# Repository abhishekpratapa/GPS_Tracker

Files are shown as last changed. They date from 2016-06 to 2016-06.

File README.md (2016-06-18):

# GPS_Tracker
A GPS tracker for a 3rd party logistics company. A medium article on how it came to be:<br/> https://medium.com/abhishek-pratapa/the-gps-tracker-842071f3ebae#.iqlriwf8i

<h2>Software</h2>

The software of the tracker consisted of an Arduino sketch and a backend initially built in Node.js however we scrapped that after we didn't have the funds to pay for the twillio api access.<br/>

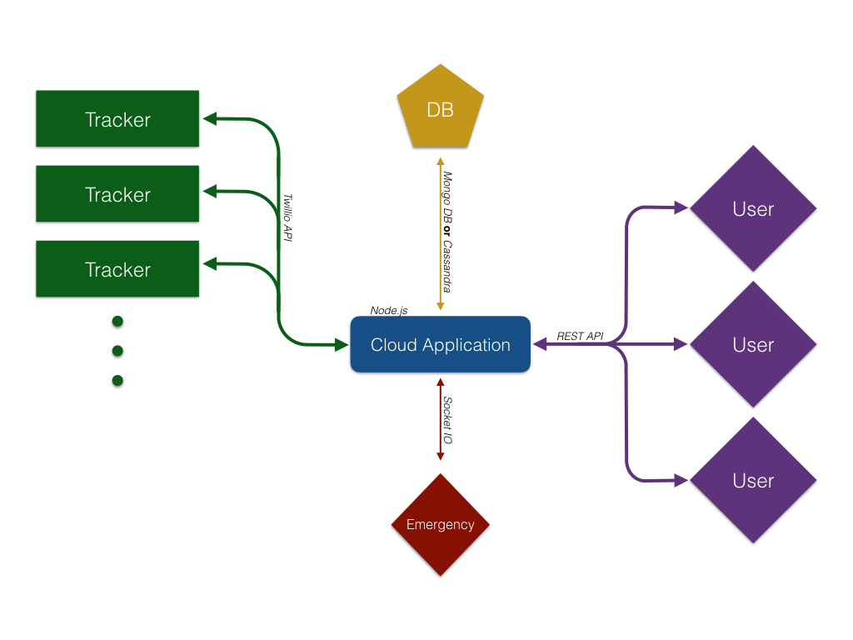
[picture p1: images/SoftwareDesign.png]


<h2>Hardware</h2>

The hardware of the tracker consisted of the below components, a full listing of parts is to follow later. <br/>

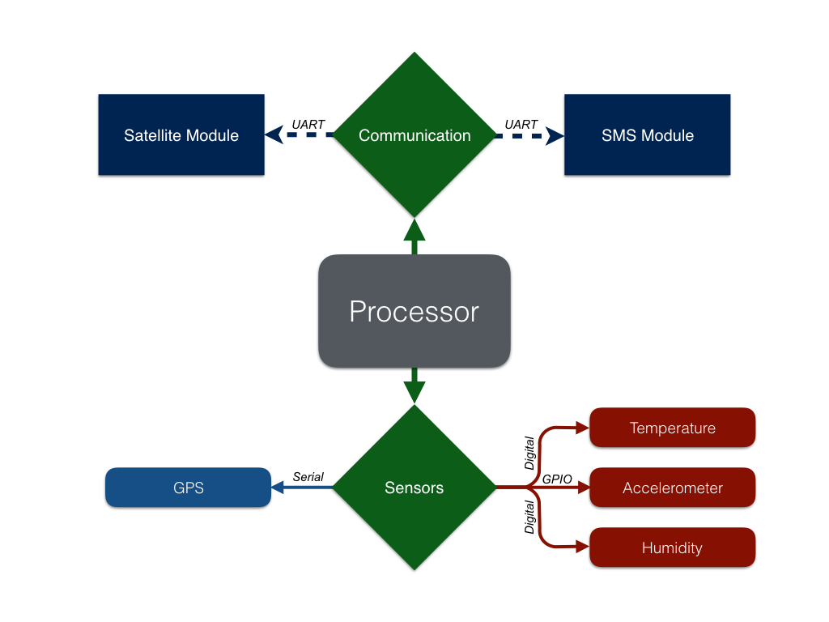
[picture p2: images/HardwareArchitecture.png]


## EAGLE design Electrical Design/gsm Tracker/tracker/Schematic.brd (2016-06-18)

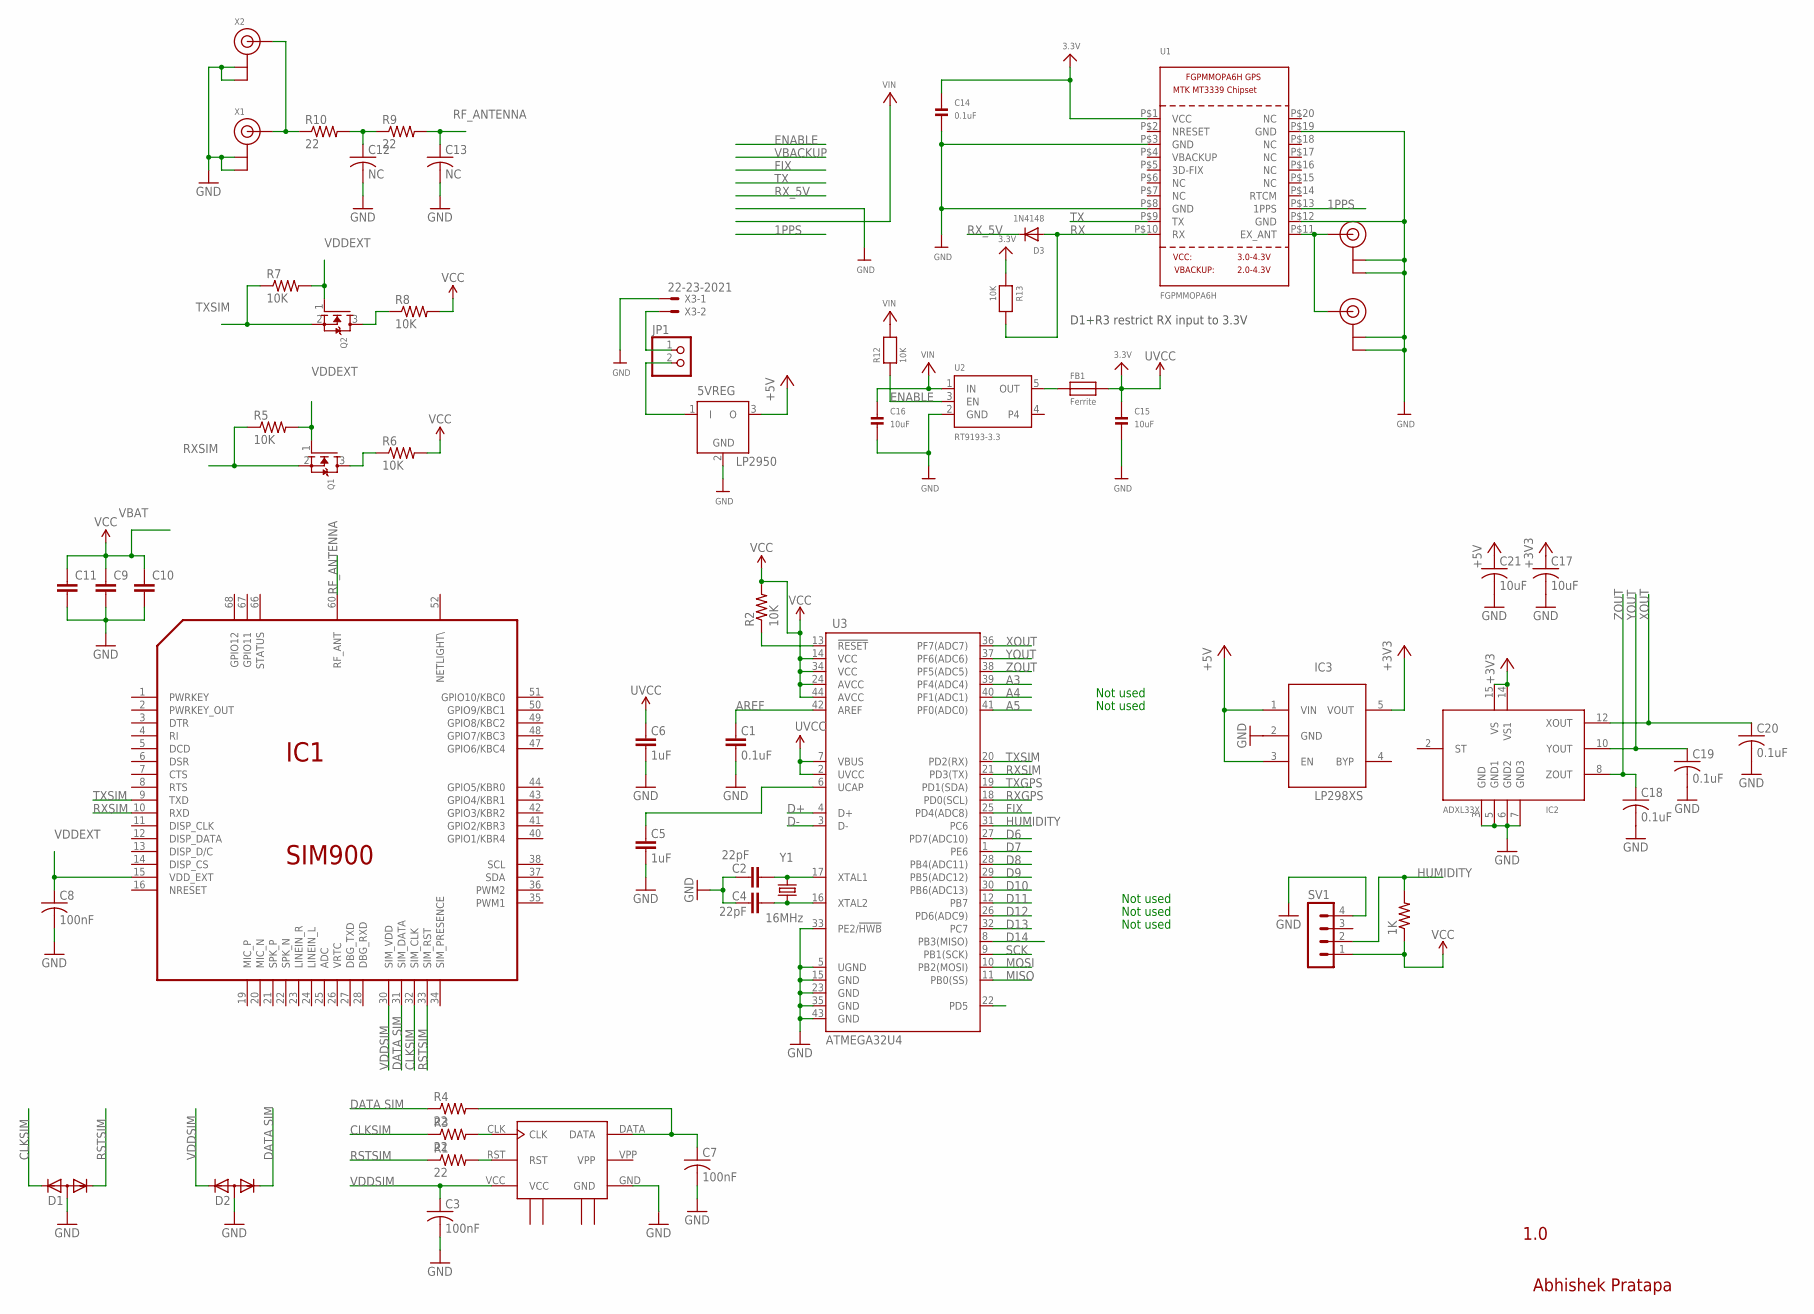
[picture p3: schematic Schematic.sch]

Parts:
1K: R-US_M0805; M0805
5VREG: LP2950; DPACK
C1: 0.1uF; 0603-CAP
C2, C4: 22pF; 0603-CAP
C3, C7, C8: 100nF; C0805
C5, C6: 1uF; 0603-CAP
C9, C10, C11: C-EUC0805; C0805
C12, C13: NC; C0805
C14: 0.1uF; 0805
C15, C16: 10uF; 0805
C17, C21: 10uF; C0805K
C18, C19, C20: 0.1uF; C0805K
D1, D2: DIODE-2CA|ACSOT23; SOT23
D3: 1N4148; SOD-323F
FB1: Ferrite; 0805
IC1: SIM900
IC2: ADXL33X; 16LCSP
IC3: LP298XS; SOT23-5L
JP1: PINHD-1X2; 1X02
Q1, Q2: MOSFET-NREFLOW; SOT23
R1, R3, R4: 22; M0805
R2: 10K; 0603-RES
R5, R6, R7, R8: 10K; M0805
R9, R10: 22; R0805
R12, R13: 10K; 0805
SV1: MA04-1
U1: FGPMMOPA6H
U2: RT9193-3.3; SOT23-5
U3: ATMEGA32U4; QFN-44-NOPAD_1:1-OUTFAKES
U$1: SCU-W0822XR-06
U$8, U$20: U.FL
X1, X2: ANTENNA_U.FL; U.FL
X3: 22-23-2021
Y1: 16MHz; CRYSTAL-SMD-5X3

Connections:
1PPS: U1.P$13 (1PPS)
3.3V: 1K.1, C14.1, C15.1, FB1.2, R13.1, SV1.1, U1.P$1 (VCC)
+3V3: C17.1, IC2.14 (VS1), IC2.15 (VS), IC3.5 (VOUT)
+5V: 5VREG.3 (O), C21.1, IC3.1 (VIN), IC3.3 (EN)
A3: U3.39 (PF4(ADC4))
A4: U3.40 (PF1(ADC1))
A5: U3.41 (PF0(ADC0))
AREF: C1.2, U3.42 (AREF)
CLKSIM: D1.2 (K2), IC1.32 (SIM_CLK), R3.1
D6: U3.27 (PD7(ADC10))
D7: U3.1 (PE6)
D8: U3.28 (PB4(ADC11))
D9: U3.29 (PB5(ADC12))
D10: U3.30 (PB6(ADC13))
D11: U3.12 (PB7)
D12: U3.26 (PD6(ADC9))
D13: U3.32 (PC7)
D14: U3.8 (PB3(MISO))
D+: U3.4 (D+)
D-: U3.3 (D-)
DATASIM: D2.1 (K1), IC1.31 (SIM_DATA), R4.1
ENABLE: R12.1, U2.3 (EN)
FIX: U3.25 (PD4(ADC8))
GND: 5VREG.2 (GND), C1.1, C2.2, C3.2, C4.2, C5.1, C6.1, C7.2, C8.2, C9.2, C10.2, C11.2, C12.2, C13.2, C14.2, C15.2, C16.2, C17.2, C18.2, C19.2, C20.2, C21.2, D1.3 (A), D2.3 (A), IC1.17 (GND), IC1.18 (GND), IC1.29 (GND), IC1.39 (GND), IC1.45 (GND), IC1.46 (GND), IC1.53 (GND), IC1.54 (GND), IC1.58 (GND), IC1.59 (GND), IC1.61 (GND), IC1.62 (GND), IC1.63 (GND), IC1.64 (GND), IC1.65 (GND), IC2.3 (GND), IC2.5 (GND1), IC2.6 (GND2), IC2.7 (GND3), IC3.2 (GND), SV1.4, U1.P$3 (GND), U1.P$8 (GND), U1.P$12 (GND), U1.P$19 (GND), U2.2 (GND), U3.5 (UGND), U3.15 (GND), U3.23 (GND), U3.33 (PE2/!HWB), U3.35 (GND), U3.43 (GND), U$1.GND, U$1.GND_1 (GND1), U$1.GND_2 (GND2), U$1.GND_3 (GND3), U$8.P$1 (GND), U$8.P$2 (GND), U$20.P$1 (GND), U$20.P$2 (GND), X1.1 (GND), X1.2 (GND), X2.1 (GND), X2.2 (GND), X3.1
GND4: U$1.GND_4 (GND4)
HUMIDITY: 1K.2, SV1.2, U3.31 (PC6)
MISO: U3.11 (PB0(SS))
MOSI: U3.10 (PB2(MOSI))
unnamed: C4.1, U3.16 (XTAL2), Y1.1
unnamed: C2.1, U3.17 (XTAL1), Y1.3 (2)
unnamed: R1.2, U$1.RST
unnamed: C5.2, U3.6 (UCAP)
unnamed: R3.2, U$1.CLK
unnamed: C7.1, R4.2, U$1.DATA
unnamed: R10.1, X1.3 (SIGNAL), X2.3 (SIGNAL)
unnamed: C12.1, R9.1, R10.2
unnamed: Q1.3 (D), R6.1
unnamed: Q2.3 (D), R8.1
unnamed: 5VREG.1 (I), JP1.2
unnamed: FB1.1, U2.5 (OUT)
unnamed: U1.P$11 (EX_ANT), U$8.P$3 (SIGNAL), U$20.P$3 (SIGNAL)
unnamed: JP1.1, X3.2
RESET: R2.1, U3.13 (!RESET)
RF_ANTENNA: C13.1, IC1.60 (RF_ANT), R9.2
RSTSIM: D1.1 (K1), IC1.33 (SIM_RST), R1.1
RX: D3.A, R13.2, U1.P$10 (RX)
RXSIM: IC1.10 (RXD), Q1.2 (S), R5.1, U3.21 (PD3(TX))
RX_5V: D3.C, U3.18 (PD0(SCL))
SCK: U3.9 (PB1(SCK))
TX: U1.P$9 (TX), U3.19 (PD1(SDA))
TXLED: U3.22 (PD5)
TXSIM: IC1.9 (TXD), Q2.2 (S), R7.1, U3.20 (PD2(RX))
UVCC: C6.2, U3.2 (UVCC), U3.7 (VBUS)
VBAT: IC1.55 (VBAT), IC1.56 (VBAT), IC1.57 (VBAT)
VCCSIM: C3.1, D2.2 (K2), IC1.30 (SIM_VDD), U$1.VCC
VDDEXT: C8.1, IC1.15 (VDD_EXT), Q1.1 (G), Q2.1 (G), R5.2, R7.2
VIN: C9.1, C10.1, C11.1, C16.1, R2.2, R6.2, R8.2, R12.2, U2.1 (IN), U3.14 (VCC), U3.24 (AVCC), U3.34 (VCC), U3.44 (AVCC)
VPP: U$1.VPP
XOUT: C20.1, IC2.12 (XOUT), U3.36 (PF7(ADC7))
YOUT: C19.1, IC2.10 (YOUT), U3.37 (PF6(ADC6))
ZOUT: C18.1, IC2.8 (ZOUT), U3.38 (PF5(ADC5))

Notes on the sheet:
Not used
DATA SIM
VDDSIM
CLKSIM
RSTSIM
VBAT
D1+R3 restrict RX input to 3.3V
TXGPS
RXGPS
Abhishek Pratapa
1.0

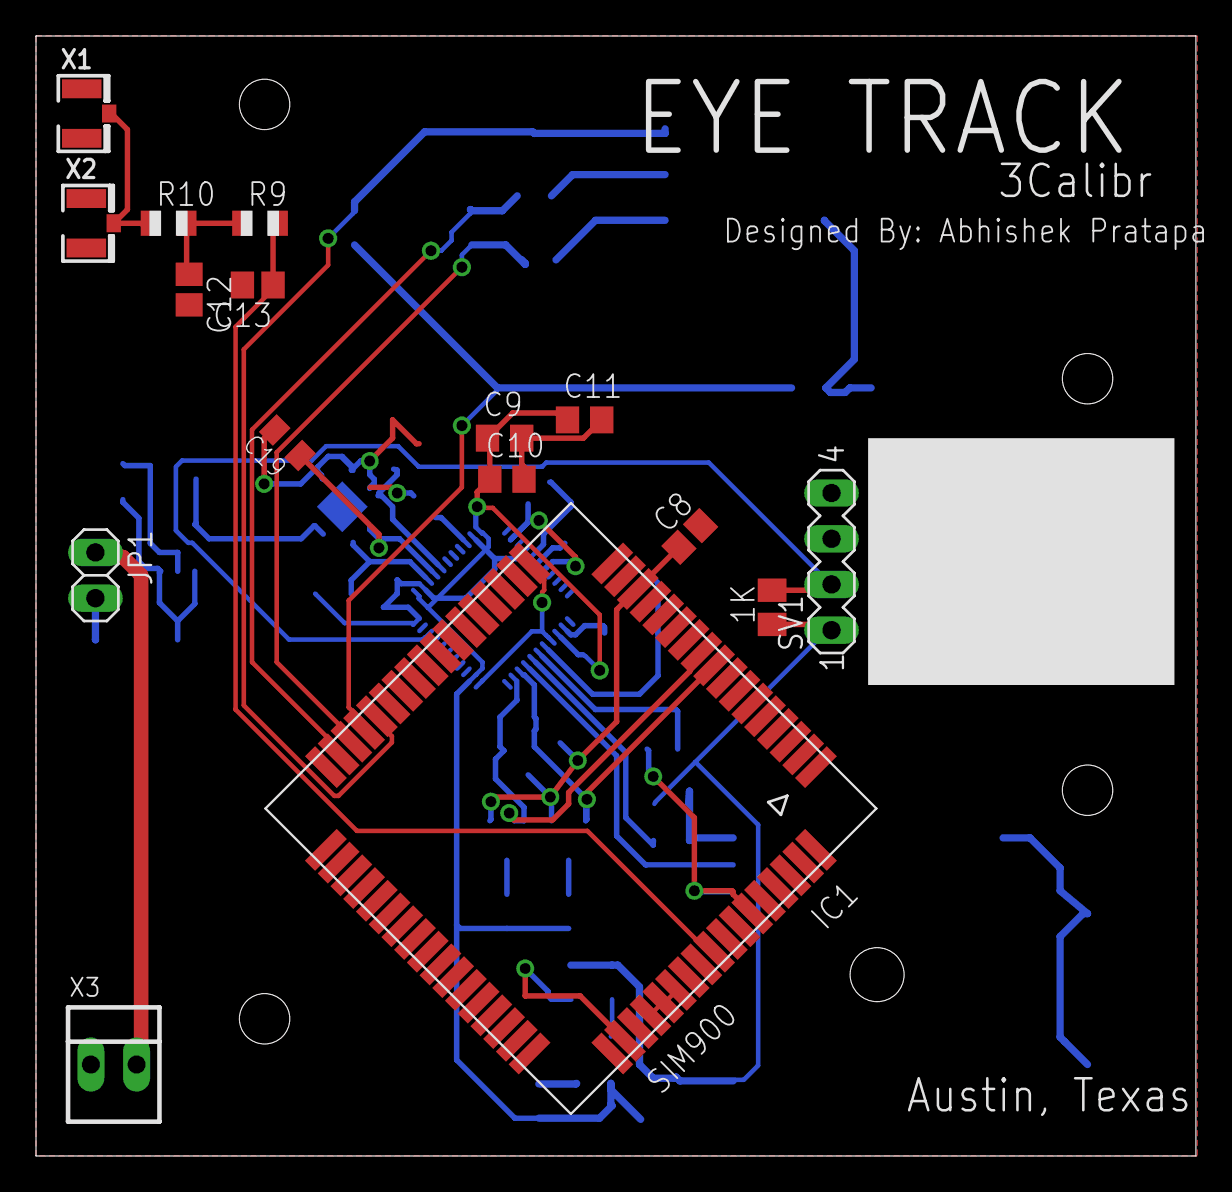
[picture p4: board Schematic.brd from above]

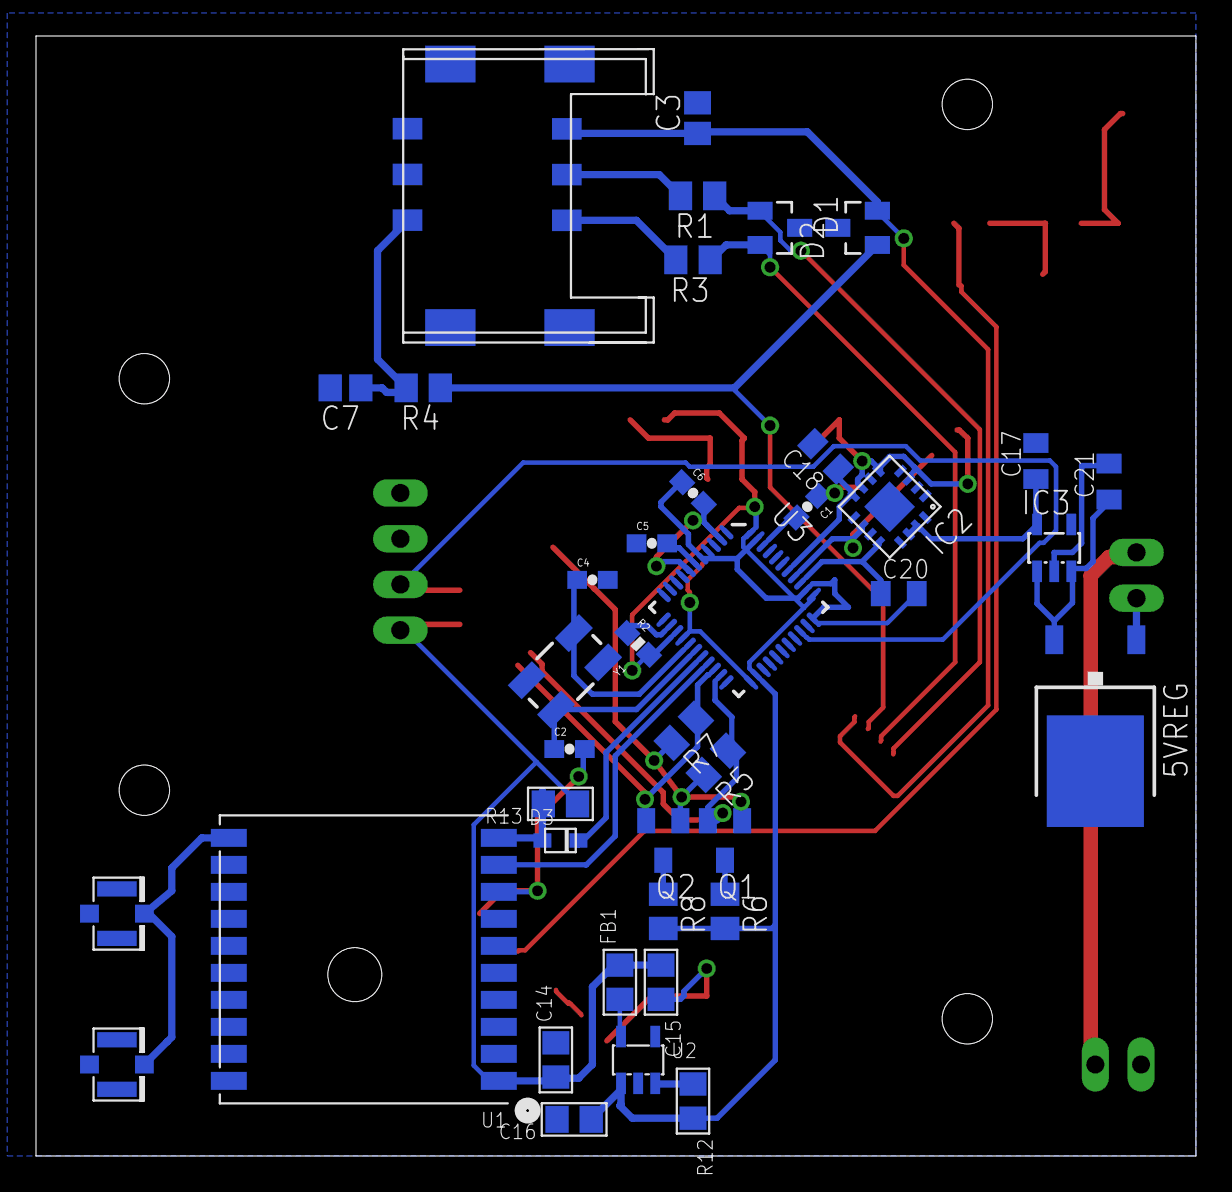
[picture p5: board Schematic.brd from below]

Board: 2 copper layers, 64.4 x 62.2 mm, 56 parts (40 on the bottom side), 39 nets.

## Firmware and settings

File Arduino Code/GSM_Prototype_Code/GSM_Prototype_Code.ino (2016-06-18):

#include <SoftwareSerial.h>
#include <HardwareSerial.h>
#include "Adafruit_FONA.h"
#include <math.h>
#include "DHT.h"

#include <Adafruit_NeoPixel.h>
#ifdef __AVR__
  #include <avr/power.h>
#endif

#define PIN            7

#define NUMPIXELS      12

#define DHTPIN 8
#define FONA_RX 0
#define FONA_TX 1
#define FONA_RST 4

#define DHTTYPE DHT22

DHT dht(DHTPIN, DHTTYPE,27);
// this is a large buffer for replies
char replybuffer[255];
char *s1 = "00:40-";
char *s2 = "15:40-";
char *s3 = "30:40-";
char *s4 = "45:40-";
int sender = 0;

//this is the communication for the fona
#define HWSERIAL Serial1
HardwareSerial fonaSerial = Serial1;
Adafruit_FONA fona = Adafruit_FONA(FONA_RST);

//check version of arduino 
#if (ARDUINO >= 100)
 #include "Arduino.h"
  #ifdef SERIAL_PORT_USBVIRTUAL
    #include <HardwareSerial.h>
  #else
    #include <SoftwareSerial.h>
  #endif
#else
 #include "WProgram.h"
 #include <NewSoftSerial.h>
#endif

const int xpin = A4;                  // x-axis of the accelerometer
const int ypin = A5;                  // y-axis of the accelerometer
const int zpin = A6;                  // z-axis of the accelerometer
char buffer[23];

uint8_t readline(char *buff, uint8_t maxbuff, uint16_t timeout = 0);
uint8_t type;

//check current battery
uint16_t currentVoltage = 0;

//neopixel object setup
Adafruit_NeoPixel pixels = Adafruit_NeoPixel(NUMPIXELS, PIN, NEO_GRB + NEO_KHZ800);

int delayval = 500;

//debounced push button code
const int buttonPin = 16;     // the number of the pushbutton pin
const int ledPin =  13;      // the number of the LED pin
int ledState = HIGH;         // the current state of the output pin
int buttonState;             // the current reading from the input pin
int lastButtonState = LOW;   // the previous reading from the input pin
int zedr = 0;
int state = 0;
int previousState = -1;
long lastDebounceTime = 0;  // the last time the output pin was toggled
long debounceDelay = 50;    // the debounce time; increase if the output flickers
int zeder = 5;
int change = 1;
int maxVal = 50;
int zedtestingErr = 1;

//Store the humidity, temperature (Celcius and Fahrenheit), and heatindex
float h;
float t;
float f;
float hi;

void setup() {
  //debugging (Uncomment for production)
  while (!Serial);
  
  Serial.begin(9600);
  Serial.println(F("FONA basic test"));
  Serial.println(F("Initializing....(May take 3 seconds)"));

  fonaSerial.begin(4800);
  if (! fona.begin(fonaSerial)) {
    Serial.println(F("Couldn't find FONA"));
    while (1);
  }
  type = fona.type();
  Serial.println(F("FONA is OK"));
  Serial.print(F("Found "));
  switch (type) {
    case FONA800L:
      Serial.println(F("FONA 800L")); break;
    case FONA800H:
      Serial.println(F("FONA 800H")); break;
    case FONA808_V1:
      Serial.println(F("FONA 808 (v1)")); break;
    case FONA808_V2:
      Serial.println(F("FONA 808 (v2)")); break;
    case FONA3G_A:
      Serial.println(F("FONA 3G (American)")); break;
    case FONA3G_E:
      Serial.println(F("FONA 3G (European)")); break;
    default: 
      Serial.println(F("???"));
      break;
  }
  
  
  // Print module IMEI number.
  char imei[15] = {0}; // MUST use a 16 character buffer for IMEI!
  uint8_t imeiLen = fona.getIMEI(imei);
  if (imeiLen > 0) {
    Serial.print("Module IMEI: "); Serial.println(imei);
  }
  
  pixels.begin();
  pinMode(buttonPin, INPUT);
  pinMode(ledPin, OUTPUT);
  
  dht.begin();
  initalize();
}

void repeatMe() {
   zedtestingErr = 1;
}

//get if the GPS and Cellular are working
int networkStatus(void){
  uint8_t n = fona.getNetworkStatus();
  
  while(n != 1){
      n = fona.getNetworkStatus();
      Serial.print(F("Network status "));
      Serial.print(n);
      Serial.print(F(": "));
      if (n == 0) Serial.println(F("Not registered"));
      if (n == 1) Serial.println(F("Registered (home)"));
      if (n == 2) Serial.println(F("Not registered (searching)"));
      if (n == 3) Serial.println(F("Denied"));
      if (n == 4) Serial.println(F("Unknown"));
      if (n == 5) Serial.println(F("Registered roaming"));
      delay(2000);
  }
  zeder = 0;
      while(zeder <= maxVal)
      {
        for(int i=0;i<NUMPIXELS;i++){
          pixels.setPixelColor(i, pixels.Color(0,round(0.8*zeder),round(0.2*zeder))); // Moderately bright green color.
          delay(5); 
        }
        zeder++;
        pixels.show();
      }
      while(zeder >= 0)
      {
         for(int i=0;i<NUMPIXELS;i++){
            pixels.setPixelColor(i, pixels.Color(0,round(0.8*zeder),round(0.2*zeder))); // Moderately bright green color.
            delay(5);
         }
         zeder--;
         pixels.show();
      }
  return 1;
}

//turn on the GPS chip
int turnOnGPS(void){
  // turn GPS on
    if (!fona.enableGPS(true)){
      Serial.println(F("Failed to turn on"));
    }
    if (!fona.enableNetworkTimeSync(true)){
          Serial.println(F("Failed to enable"));
    }
    delay(3000);
      
      int8_t stat = 1;
      // check GPS fix
      
      while((stat !=  2) && (stat != 3))
      {
        stat = fona.GPSstatus();
        if (stat < 0)
          Serial.println(F("Failed to query"));
        if (stat == 0) Serial.println(F("GPS off"));
        if (stat == 1) Serial.println(F("No fix"));
        if (stat == 2) Serial.println(F("2D fix"));
        if (stat == 3) Serial.println(F("3D fix"));
        
        zeder = 2;
      while(zeder <= maxVal)
      {
        for(int i=0;i<NUMPIXELS;i++){
          pixels.setPixelColor(i, pixels.Color(round(0.3*zeder),round(0.3*zeder),round(0.3*zeder))); // Moderately bright green color.
          delay(1); 
        }
        zeder++;
        pixels.show();
      }
      while(zeder >= 2)
      {
         for(int i=0;i<NUMPIXELS;i++){
            pixels.setPixelColor(i, pixels.Color(round(0.3*zeder),round(0.3*zeder),round(0.3*zeder))); // Moderately bright green color.
            delay(1);
         }
         zeder--;
         pixels.show();
      }
        
        delay(2000);
      }
      
      zeder = 0;
      while(zeder <= maxVal)
      {
        for(int i=0;i<NUMPIXELS;i++){
          pixels.setPixelColor(i, pixels.Color(0,round(0.1*zeder),round(0.9*zeder))); // Moderately bright green color.
          delay(5); 
        }
        zeder++;
        pixels.show();
      }
      while(zeder >= 0)
      {
         for(int i=0;i<NUMPIXELS;i++){
            pixels.setPixelColor(i, pixels.Color(0,round(0.1*zeder),round(0.9*zeder))); // Moderately bright green color.
            delay(5);
         }
         zeder--;
         pixels.show();
      }
      return stat;
}

//turn on the volume
void setHeadSet(void){
        // set to headphone jack
        if (! fona.setAudio(FONA_HEADSETAUDIO)) {
          Serial.println(F("Failed"));
        } else {
          Serial.println(F("OK!"));
        }
        fona.setMicVolume(FONA_HEADSETAUDIO, 15);
        
         // set volume
        flushSerial();
        if ( (type == FONA3G_A) || (type == FONA3G_E) ) {
          Serial.print(F("Set Vol [0-8] "));
        } else {
          Serial.print(F("Set Vol % [0-100] "));
        }
        uint8_t vol = 50;
        //Serial.println();
        if (! fona.setVolume(vol)) {
          Serial.println(F("Failed"));
        } else {
          //Serial.println(F("OK!"));
        }
        
        //play a tone
        flushSerial();
        Serial.print(F("Play tone #"));
        uint8_t kittone = 20;
        Serial.println();
        // play for 1 second (1000 ms)
        if (! fona.playToolkitTone(kittone, 1000)) {
          Serial.println(F("Failed"));
        } else {
          Serial.println(F("OK!"));
        }
        
        zeder = 0;
      while(zeder <= maxVal)
      {
        for(int i=0;i<NUMPIXELS;i++){
          pixels.setPixelColor(i, pixels.Color(round(0.7*zeder),round(0.3*zeder),0)); // Moderately bright green color.
          delay(5);
        }
        zeder++;
        pixels.show();
      }
      while(zeder >= 0)
      {
         for(int i=0;i<NUMPIXELS;i++){
            pixels.setPixelColor(i, pixels.Color(round(0.7*zeder),round(0.3*zeder),0)); // Moderately bright green color.
            delay(5);
         }
         zeder--;
         pixels.show();
      }
}

//initializing script
void initalize(void) {
  //light startup
  for(int i=0;i<NUMPIXELS;i++){
    if(state == 0){
      pixels.setPixelColor(i, pixels.Color(0,zeder,0)); // Moderately bright green color.
    } else if(state == 1) {
      pixels.setPixelColor(i, pixels.Color(zeder,0,0));
    } else if(state == 2){
      pixels.setPixelColor(i, pixels.Color(0,0,zeder));
    }
    pixels.show(); // This sends the updated pixel color to the hardware.

    delay(delayval); // Delay for a period of time (in milliseconds).
    
  }
  zeder = maxVal;
  zedr = 1;
  //newtork status up
  networkStatus();
  //set mic volume
  setHeadSet();
  //turn on the GPS
  turnOnGPS();
}


//get battery reading
int getBatteryVoltage(void){
  uint16_t vbat;
  if (! fona.getBattPercent(&vbat)) {
     Serial.println(F("Failed to read Batt"));
     return -1;
  } else {
     Serial.print(F("VPct = "));
     Serial.print(vbat);
     Serial.println(F("%"));
     return (vbat+0);
  }
}

void loop() {
  delay(2000);
   //put your main code here, to run repeatedly:
   //get voltage
  uint16_t adc;
  getBatteryVoltage();
  ReadTempHumiditySensor();
  readAccloremeter();
  
  Serial.println();
  Serial.println();
  char gpsdata[120];
  fona.getGPS(0, gpsdata, 120);
  if (type == FONA808_V1)
      Serial.println(F("Reply in format: mode,longitude,latitude,altitude,utctime(yyyymmddHHMMSS),ttff,satellites,speed,course"));
      Serial.println(gpsdata);
      Serial.println();
      Serial.println();
      Serial.println();
      Serial.println();
   
   fona.getTime(buffer, 23);  // make sure replybuffer is at least 23 bytes!
   
   if((strstr(buffer, s1) != NULL) || (strstr(buffer, s2) != NULL) || (strstr(buffer, s3) != NULL) || (strstr(buffer, s4) != NULL) || (zedtestingErr == 1)){
        char sendto[21];
        char message[141];
        flushSerial();
        //Serial.print(F("Send to #"));
        sendto[0] = '5';
        sendto[1] = '1';
        sendto[2] = '2';
        sendto[3] = '9';
        sendto[4] = '8';
        sendto[5] = '3';
        sendto[6] = '1';
        sendto[7] = '7';
        sendto[8] = '6';
        sendto[9] = '7';
        Serial.println(sendto);
        Serial.print(F("Type out one-line message (140 char): "));
        strncpy(message, gpsdata, 120);
        
        Serial.println(message);
        if (!fona.sendSMS(sendto, message)) {
           for(int i=0;i<NUMPIXELS;i++){
              pixels.setPixelColor(i, pixels.Color(20,0,0));
           }
           pixels.show();
          delay(100);
           for(int i=0;i<NUMPIXELS;i++){
              pixels.setPixelColor(i, pixels.Color(0,0,0));
           }
          pixels.show();
        } else {
           for(int i=0;i<NUMPIXELS;i++){
              pixels.setPixelColor(i, pixels.Color(0,20,20));
           }
          pixels.show();
          delay(100);
           for(int i=0;i<NUMPIXELS;i++){
              pixels.setPixelColor(i, pixels.Color(0,0,0));
           }
          pixels.show();
        }
    zedtestingErr = 2;
  }
  //network status
  int reading = digitalRead(buttonPin);

  if (reading != lastButtonState) {
    lastDebounceTime = millis();
  } 
  
  if((buttonState != lastButtonState) && (millis() - lastDebounceTime) > debounceDelay)
  {
     state = (state+1)%3; 
  }
  
  if ((millis() - lastDebounceTime) > debounceDelay) {
    buttonState = reading;
    
    
  }
  if(state != previousState){
    change++;
  }
  
  
  if(state != previousState && change == 2){
    change = 0;
    while(zeder <= maxVal)
    {
      for(int i=0;i<NUMPIXELS;i++){
     
        // pixels.Color takes RGB values, from 0,0,0 up to 255,255,255
         
        if(state == 0){
          pixels.setPixelColor(i, pixels.Color(0,zeder,0)); // Moderately bright green color.
        } else if(state == 1) {
          pixels.setPixelColor(i, pixels.Color(zeder,0,0));
        } else if(state == 2){
          pixels.setPixelColor(i, pixels.Color(0,0,zeder));
        }
        pixels.show(); // This sends the updated pixel color to the hardware.
    
        //delay(delayval); // Delay for a period of time (in milliseconds).
    
      }
      zeder++;
      delay(10);
    }
    while(zeder >= 0)
    {
      for(int i=0;i<NUMPIXELS;i++){
     
        // pixels.Color takes RGB values, from 0,0,0 up to 255,255,255
         
        if(state == 0){
          pixels.setPixelColor(i, pixels.Color(0,zeder,0)); // Moderately bright green color.
        } else if(state == 1) {
          pixels.setPixelColor(i, pixels.Color(zeder,0,0));
        } else if(state == 2){
          pixels.setPixelColor(i, pixels.Color(0,0,zeder));
        }
        pixels.show(); // This sends the updated pixel color to the hardware.
    
        //delay(delayval); // Delay for a period of time (in milliseconds).
    
      }
      zeder--;
      delay(10);
    }
  }
  zeder = 0;
  if(zedr == 1)
  {
    digitalWrite(ledPin, HIGH);
    delay(1000);
    digitalWrite(ledPin, LOW);
    zedr++;
  }
  
  previousState = state;
  // save the reading.  Next time through the loop,
  // it'll be the lastButtonState:
  lastButtonState = reading;
   
}

int readAccloremeter(){
  Serial.println();
  Serial.println();
  Serial.println("Accloremeter");
  // print the sensor values:
  Serial.print(analogRead(xpin));
  // print a tab between values:
   Serial.print("\t");
   Serial.print(analogRead(ypin));
  // print a tab between values:
  Serial.print("\t");
  Serial.print(analogRead(ypin));
  Serial.println();
  // delay before next reading:
  delay(100);
}

int ReadTempHumiditySensor(){
  // Reading temperature or humidity takes about 250 milliseconds
  // Sensor readings may also be up to 2 seconds, its a very slow sensor
  float h = dht.readHumidity();
  // Read temperature as Celsius
  float t = dht.readTemperature();
  // Read temperature as Fahrenheit
  float f = dht.readTemperature(true);
  
  if (isnan(h) || isnan(t) || isnan(f)) {
    Serial.println("Failed to read from DHT sensor!");
    return 1;
  }
  
  hi = dht.computeHeatIndex(f, h);
  
  Serial.print("Humidity: "); 
  Serial.print(h);
  Serial.print(" %\t");
  Serial.print("Temperature: "); 
  Serial.print(t);
  Serial.print(" *C ");
  Serial.print(f);
  Serial.print(" *F\t");
  Serial.print("Heat index: ");
  Serial.print(hi);
  Serial.println(" *F");
  return 0;
}

void flushSerial() {
  while (Serial.available())
    Serial.read();
}

char readBlocking() {
  return 'a';
}
uint16_t readnumber() {
  uint16_t x = 0;
  char c;
  while (! isdigit(c = readBlocking())) {
    //loop
  }
  x = c - '0';
  while (isdigit(c = readBlocking())) {
    x *= 10;
    x += c - '0';
  }
  return x;
}

uint8_t readline(char *buff, uint8_t maxbuff, uint16_t timeout) {
  uint16_t buffidx = 0;
  boolean timeoutvalid = true;
  if (timeout == 0) timeoutvalid = false;

  while (true) {
    if (buffidx > maxbuff) {
      break;
    }

    if (timeoutvalid && timeout == 0) {
      break;
    }
    delay(1);
  }
  buff[buffidx] = 0;
  return buffidx;
}

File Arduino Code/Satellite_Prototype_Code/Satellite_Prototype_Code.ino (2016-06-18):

#include <Adafruit_NeoPixel.h>
#include <avr/power.h>
#include <IridiumSBD.h>
#include <SoftwareSerial.h>
#include <TinyGPS.h>
#include <dht.h>
#include <PString.h>

//setup neopixel variables
#define DHT22_PIN 10
#define ss Serial3
#define nss Serial1
#define PIN            9
#define NUMPIXELS      12

//set up accelerometer values
const int xpin = A4;
const int ypin = A5;
const int zpin = A6;

//a time variable
int time = 0;

//the temperature and humidity sensor object
dht DHT;

struct
{
    uint32_t total;
    uint32_t ok;
    uint32_t crc_error;
    uint32_t time_out;
    uint32_t connect;
    uint32_t ack_l;
    uint32_t ack_h;
    uint32_t unknown;
} stat = { 0,0,0,0,0,0,0,0};

//the gps module pin
TinyGPS gps;
int pin = 4;
unsigned long durationHIGH;
unsigned long durationLOW;
long durationtot;
boolean fixFound = false;

long sleepit;

//getting the gps latitude and longitude values
float hereGPSflat;
float hereGPSflon;

//connecting te satillite chips
IridiumSBD isbd(nss, 3);
static const int ledPin = 13;

long xrror = 1;

//creating Neopixel Object
Adafruit_NeoPixel pixels = Adafruit_NeoPixel(NUMPIXELS, PIN, NEO_GRB + NEO_KHZ800);
int delayval = 500;

//setting up the Microcontroller
void setup() {
  #if defined (__AVR_ATtiny85__)
    if (F_CPU == 16000000) clock_prescale_set(clock_div_1);
  #endif
  
  int signalQuality = -1;

  pinMode(ledPin, OUTPUT);

  nss.begin(19200);

  isbd.attachConsole(Serial);
  isbd.setPowerProfile(1);
  isbd.begin();
  
  Serial.begin(115200);
  pinMode(pin, INPUT);
  ss.begin(9600);
  
  pixels.begin();
  GPSSetup();
}

//set up gps signal and satillite signal
void GPSSetup(){
  for(int j = 0; j < 25; j = j+1){
        for(int i=0;i<NUMPIXELS;i++){
         pixels.setPixelColor(i, pixels.Color(j,j,j)); // Moderately bright white color.
         pixels.show();
        }
       delay(1);
    }
    delay(2000);
    for(int j = 24; j >= 0; j = j-1){
        for(int i=0;i<NUMPIXELS;i++){
         pixels.setPixelColor(i, pixels.Color(j,j,j)); // Moderately bright white color.
         pixels.show();
        }
       delay(1);
    }
    
  while(!fixFound){
    while(digitalRead(pin) == HIGH){
      durationHIGH = millis();
    }
    while(digitalRead(pin) == LOW){
      durationLOW = millis();
    }
    durationtot = durationLOW - durationHIGH;
    durationtot = abs(durationtot);
    durationtot = durationtot/1000;
    Serial.println(durationtot);
    if(durationtot > 10 && time > 2){
      fixFound = true;
    }
    time++;
    delay(200);
  }
  
    for(int j = 0; j <= 25; j = j+1){
        for(int i=0;i<NUMPIXELS;i++){
         pixels.setPixelColor(i, pixels.Color(0,0,j)); // Moderately bright green color.
         pixels.show();
        }
       delay(1);
    }
    delay(2000);
    
    for(int j = 24; j >= 0; j = j-1){
        for(int i=0;i<NUMPIXELS;i++){
         pixels.setPixelColor(i, pixels.Color(0,0,j)); // Moderately bright green color.
         pixels.show();
        }
       delay(1);
    }
    
  sleepit = millis() - 14400000;
  return;
}

void loop() {
  if((millis()-sleepit) > 14400000){
    int signalQuality = -1;
    isbd.begin();
    int err = isbd.getSignalQuality(signalQuality);
    bool newData = false;
    //gps check
    unsigned long chars;
    unsigned short sentences, failed;
  
    // For one second we parse GPS data and report some key values
    for (unsigned long start = millis(); millis() - start < 1000;)
    {
      while (ss.available())
      {
        char c = ss.read();
        // Serial.write(c); // uncomment this line if you want to see the GPS data flowing
        if (gps.encode(c)) // Did a new valid sentence come in?
          newData = true;
      }
    }
  
    if (newData)
    {
      float flat, flon;
      unsigned long age;
      gps.f_get_position(&flat, &flon, &age);
      Serial.print("LAT=");
      Serial.print(flat == TinyGPS::GPS_INVALID_F_ANGLE ? 0.0 : flat, 6);
      Serial.print(" LON=");
      Serial.print(flon == TinyGPS::GPS_INVALID_F_ANGLE ? 0.0 : flon, 6);
      Serial.print(" SAT=");
      Serial.print(gps.satellites() == TinyGPS::GPS_INVALID_SATELLITES ? 0 : gps.satellites());
      Serial.print(" PREC=");
      Serial.print(gps.hdop() == TinyGPS::GPS_INVALID_HDOP ? 0 : gps.hdop());
      hereGPSflat = flat;
      hereGPSflon = flon;
    }
    
    gps.stats(&chars, &sentences, &failed);
    
    Serial.print("DHT22, \t");

    uint32_t start = micros();
    int chk = DHT.read22(DHT22_PIN);
    uint32_t stop = micros();

    stat.total++;
    switch (chk)
    {
    case DHTLIB_OK:
        stat.ok++;
        Serial.print("OK,\t");
        break;
    case DHTLIB_ERROR_CHECKSUM:
        stat.crc_error++;
        Serial.print("Checksum error,\t");
        break;
    case DHTLIB_ERROR_TIMEOUT:
        stat.time_out++;
        Serial.print("Time out error,\t");
        break;
    default:
        stat.unknown++;
        Serial.print("Unknown error,\t");
        break;
    }
    // DISPLAY DATA
    Serial.print(DHT.humidity, 1);
    Serial.print(",\t");
    Serial.print(DHT.temperature, 1);
    Serial.print(",\t");
    Serial.print(stop - start);
    Serial.println();
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
